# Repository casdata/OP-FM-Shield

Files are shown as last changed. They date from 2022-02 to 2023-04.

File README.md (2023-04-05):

# OP-FM-Shield
FM Synthesizer and VGM player for the Arduino Due

<p align="center">
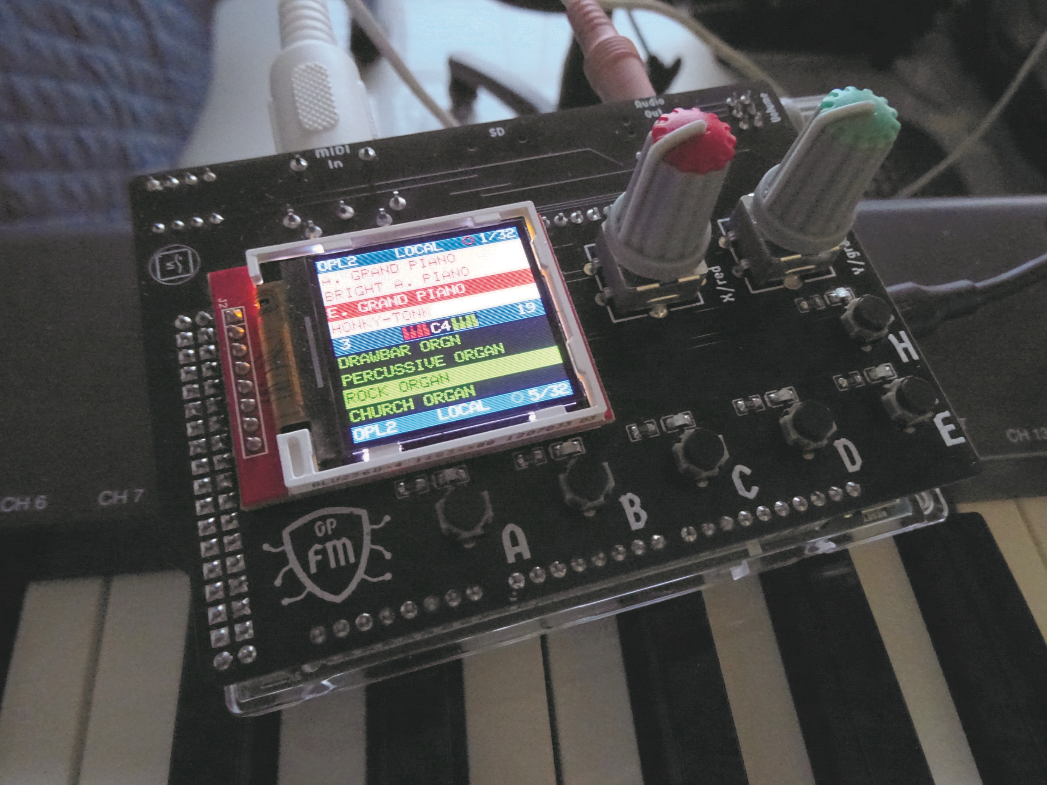
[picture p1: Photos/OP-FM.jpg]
  
</p>
                                                                                                     

The OP-FM Shield is an FM synthesizer and VGM player for the Arduino Due development board, it’s powered by the YMF262 (OPL3) sound chip from Yamaha. Is compatible with any keyboard with a 5 pin MIDI OUT port.

In Synth mode, the YMF262 can work in OPL2 or OPL3 mode depending on the selected voice, a maximum of 12 keys can be pressed simultaneously in OPL2 and 6 keys for OPL3. New OPL2 and OPL3 voices can be created from scratch, also the Included voices in the firmware can be modified, the user has access to almost all the parameters of the YMF262, why almost all? The five native rhythms are not available. 

Synth mode has two options on how the keyboard can be used, in the first option (first screen) the synth uses all the keyboards for the selected voice, in the second option, the keyboard is divided into two, one-half keyboard for red voice and the other half for the green voice, an OPL3 voice can only be selected in the red voice half and the maximum number of simultaneous keys are downgraded to five. 

In VGM player mode the keyboard is disabled, all the VGM songs are readed from the SD card. This mode also has the option to extract the voices of the VGM, they’re stored in a temporary folder that can be accessed from synth mode, those extracted voices must be saved manually or they’re deleted when other voices are extracted from a VGM.

VGM files for the OPL, OPL2 and OPL3 are compatible with the OP-FM, songs can be found on the internet, but before the .vgm file is transferred to the “vgm” folder in the SD card, the file must be extracted using the 7-zip app (https://www.7-zip.org).

And the best part above all is that software and hardware parts of the OP-FM Shield are open source, enjoy!

### Recommended VGM websites: 
* https://opl.wafflenet.com
* https://vgmrips.net/packs/chip/ymf262

## Board
Front            |  Back
:-------------------------:|:-------------------------:
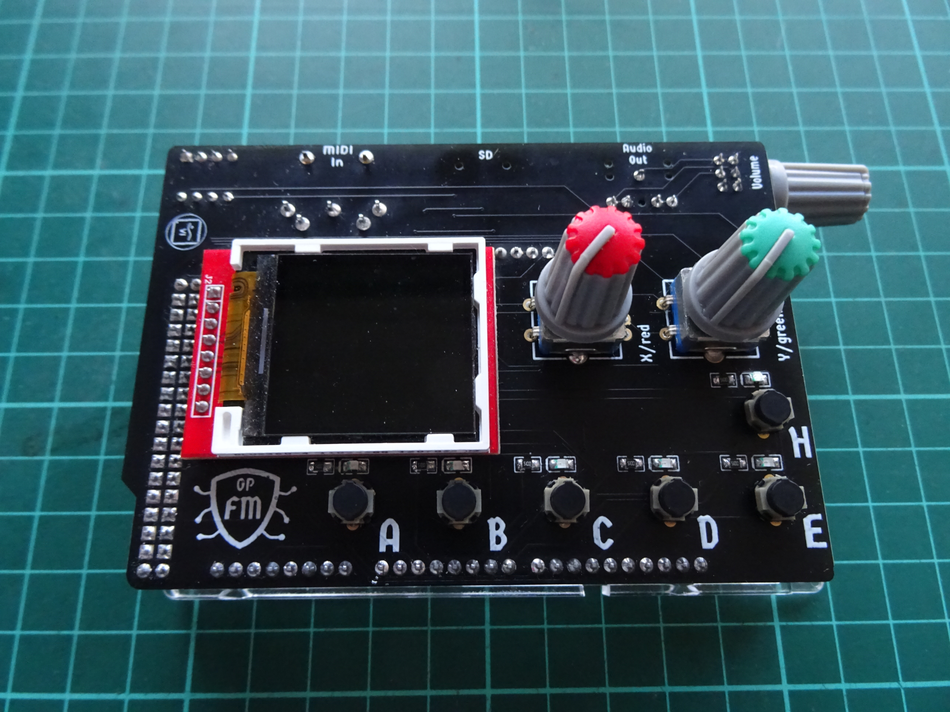
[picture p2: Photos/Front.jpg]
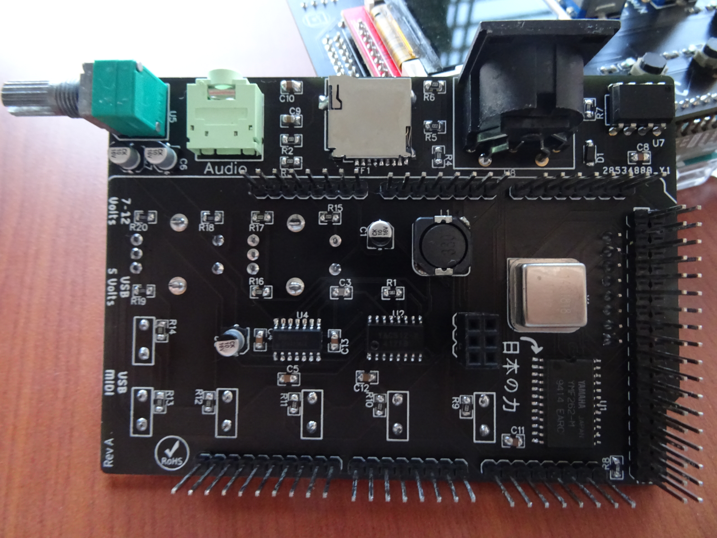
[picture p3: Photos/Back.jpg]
  |  

## Schematic Diagram
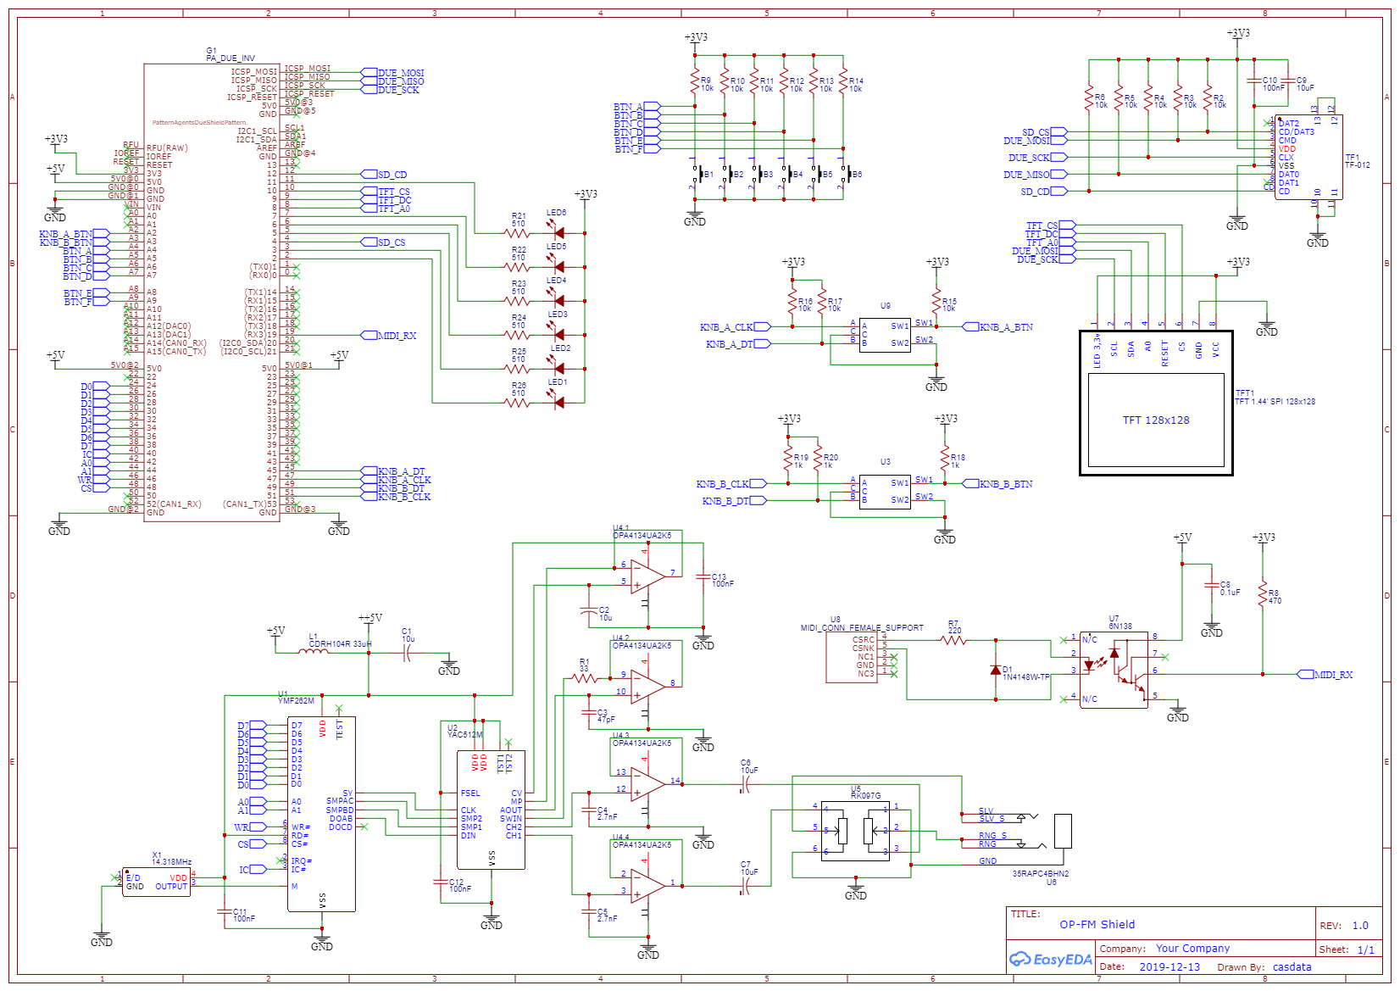
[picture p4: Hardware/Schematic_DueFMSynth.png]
Schematic
                                                                                                     
## Required Arduino Libraries
Before the firmware is uploaded, these libraries must be installed:
* MIDI Library by Francois Best (https://github.com/FortySevenEffects/arduino_midi_library)
* Adafruit GFX Library by Adafruit (https://github.com/adafruit/Adafruit-GFX-Library)
* Adafruit BusIO (https://github.com/adafruit/Adafruit_BusIO)
* Adafruit ST7735 and ST7789 Library by Adafruit (https://github.com/adafruit/Adafruit-ST7735-Library)
* Adafruit seesaw Library by Adafruit (https://github.com/adafruit/Adafruit_Seesaw)
* SD by Arduino, SparkFun (https://github.com/arduino-libraries/SD)
* Encoder by Paul Stoffregen (https://github.com/PaulStoffregen/Encoder)
* ArduinoThread by Ivan Seidel (https://github.com/ivanseidel/ArduinoThread)
* DueTimer by Ivan Seidel (https://github.com/ivanseidel/DueTimer)

## Alternative Firmware Download
The code for the firmware is available in the 'Software" folder but can also be downloaded from the Arduino Cloud (https://create.arduino.cc/editor/casdata/655ca870-2cc1-4bf0-9da4-6e03262c0709/preview)

## IMPORTANT
The shield works either with the original or the Chinese clones Arduino Due boards, but it’s recommended to use the original due to some clone boards (almost all) comes with an issue in the power supply circuit that induces noise into the MIDI port when powering it over the power jack, also in the clone boards the shield doesn't boot until the reset button in the Arduino board is pressed after its connected to a power source.

## Contact

Sergio Daniel Castañeda N. - [@twitter_handle](https://twitter.com/CasdataSergio) - casdata@gmail.com

Website: http://casnisoft.weebly.com

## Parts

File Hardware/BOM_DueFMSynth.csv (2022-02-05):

ID | Name | Designator | Footprint | Quantity | Manufacturer Part | Manufacturer | Supplier | Supplier Part | Price
1 | PUSH_BUTTON_2Pini | B1,B2,B3,B4,B5,B6 | PUSH2 | 6 | PUSH_BUTTON_2Pini
2 | 10u | C1,C2 | CAP-D4.0XH5.5 | 2
3 | 47pF | C3 | 0805 | 1
4 | 2.7nF | C4,C5 | 0805 | 2
5 | 10uF | C6,C7 | CAP-D4.0XH5.5 | 2
6 | 0.1uF | C8 | 0805 | 1
7 | 10uF | C9 | 0805 | 1
8 | 100nF | C10,C11,C12,C13 | 0805 | 4
9 | 1N4148W-TP | D1 | SOD-123_L2.8-W1.8-LS3.7-RD | 1 | 1N4148W-TP | MCC | LCSC | C77978 | 0.014
10 | PA_DUE_INV | G1 | PA_DUE_INV | 1 |  | Arduino
11 | CDRH104R 33uH | L1 | CDRH104R | 1 | CDRH104R
12 | 17-21SURC/S530-A2/TR8 | LED1,LED2,LED3,LED4,LED5,LED6 | LED-0805 | 6 | 17-21SURC/S530-A2/TR8 | EVERLIGHT | LCSC | C131244 | 0.023
13 | 33 | R1 | 0805 | 1
14 | 10k | R2,R3,R4,R5,R6,R9,R10,R11,R12,R13,R14,R15,R16,R17 | 0805 | 14
15 | 220 | R7 | 0805 | 1
16 | 470 | R8 | 0805 | 1
17 | 1k | R18,R19,R20 | 0805 | 3
18 | 510 | R21,R22,R23,R24,R25,R26 | 0805 | 6
19 | TF-012 | TF1 | TF-SMD_TF-012 | 1 | TF-012 | Hanbo Electronic | LCSC | C410350 | 0.245
20 | TFT 1.44' SPI 128x128 | TFT1 | TFT_1.44'_SPI_128X128 | 1 | TFT_ILI9163C
21 | YMF262M | U1 | SOP24 | 1
22 | YAC512M | U2 | SOP-16_L10.0-W3.9-P1.27-LS6.0-BL | 1
23 | Rotary Encoder knob | U3,U9 | ROTARY_ENCODER | 2 | Rotary Encoder
24 | RK097G | U5 | RK097G | 1 | RK097G
25 | 35RAPC4BHN2 | U6 | 35RAPC4BHN2 | 1
26 | 6N138 | U7 | DIP-8_L9.8-W6.6-P2.54-LS7.6-BL | 1 | 6N138 | Isocom Components | LCSC | C255743 | 0.634
27 | MIDI_CONN_FEMALE_SUPPORT | U8 | DIN_5_FEMALE_SUPPORT | 1
28 | 14.318MHz | X1 | DIP_4P | 1
29 | OPA4134UA2K5 | U4 | SOIC14N | 1

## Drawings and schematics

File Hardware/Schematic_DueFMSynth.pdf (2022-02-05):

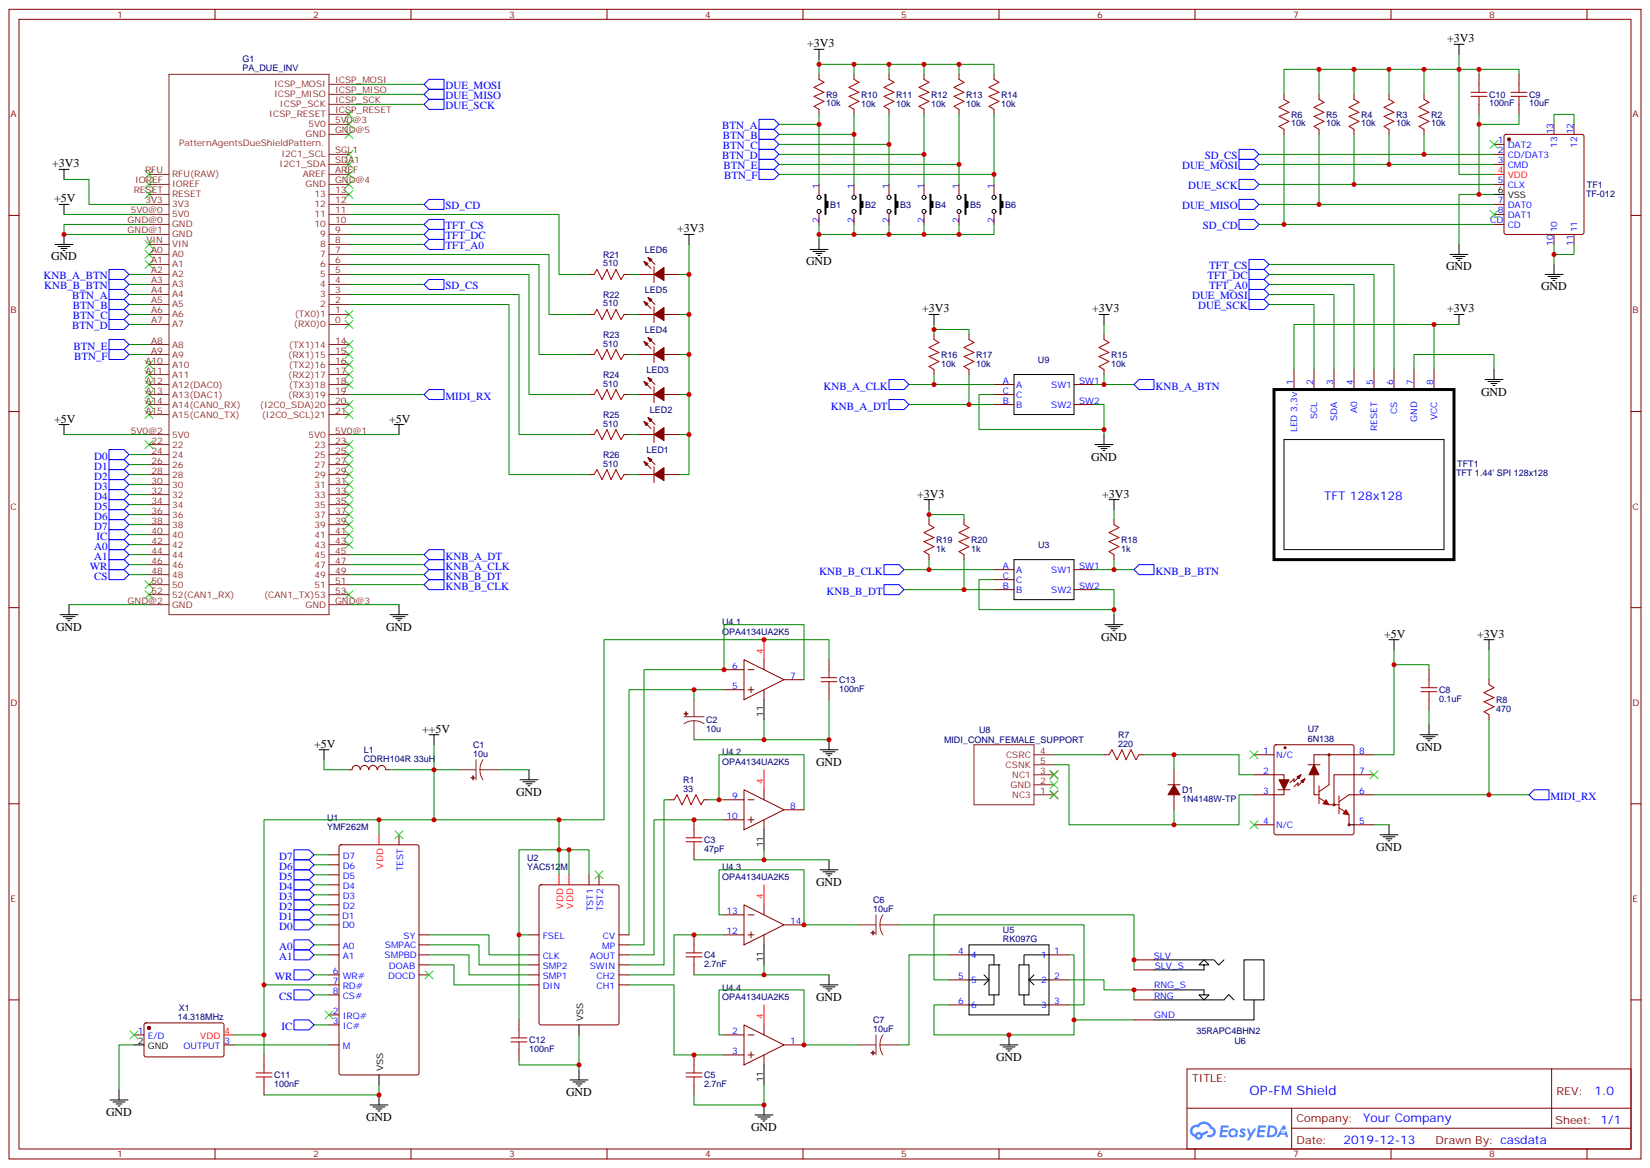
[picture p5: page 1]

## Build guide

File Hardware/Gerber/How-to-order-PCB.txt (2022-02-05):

How to Order PCB

Please refer to:
https://docs.easyeda.com/en/PCB/Order-PCB

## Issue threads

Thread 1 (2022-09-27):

the model of Rotary Encoder

Landau-Randall, 2022-09-27:
could you tell me the model of rotary Encoder knob?

casdata, 2022-09-29:
Hi Landau-Randall,  the model is the EC11, you can find it in [Aliexpress ](https://www.aliexpress.com/item/4000755931777.html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,scm-url:1007.13339.291025.0,pvid:340e41b6-d87d-4f35-93a1-3b553f208879,tpp_buckets:668%232846%238113%231998&pdp_ext_f=%7B"sku_id"%3A"10000007329345591"%2C"sceneId"%3A"3339"%7D&pdp_npi=2%40dis%21USD%212.72%212.72%21%21%21%21%21%40210312ee16644289897832056e1a16%2110000007329345591%21rec)

Ming-Kerr, 2023-04-04:
Hello.
I just completed a build and it booted first go.
I chose EC11 24 indent full step and have a strange problem.
The encoders turn the opposite way they are supposed to.
Is there an easy fix in the code to reverse the rotation direction?
Cheers.
Phil.

Ming-Kerr, 2023-04-04:
To solve my own problem, lol, I found the part in the code and reversed the logic:

void checkLimitOfKnob(int selectedKnob){

    switch(selectedKnob){
        case 0:
        if(knobACount < 0){
            knobACount = 0;
            knobA.write(0);
            **knobARight** = true;
        }
        else if(knobACount > 0){
            knobACount = 0;
            knobA.write(0);
            **knobALeft** = true;
            //knobA.write(maxLimit * 2);
        }
        break;
        case 1:
        if(knobBCount < 0){
            knobBCount = 0;
            knobB.write(0);
            **knobBRight** = true;
        }
        else if(knobBCount > 0){
            knobBCount = 0;
            knobB.write(0);
            **knobBLeft** = true;
            //knobB.write(maxLimit * 2);
        }
        break;
    }

casdata, 2023-04-05:
Hi Ming-Kerr, thanks for pointing out the issue and solving it.

Closed 2023-04-05.

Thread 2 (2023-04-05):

Versions used in compile

Ming-Kerr, 2023-04-05:
Hello.
Can you reply with the versions used for compile: Arduino IDE and the main include libraries please?

I cannot get the software to read the SDcard and have had this problem before in other apps due to library versions incompatibility.

Thanks.

casdata, 2023-04-05:
Hi Mr. Ming-Kerr, I just compile and test the board on a PC without Arduino, a clean install, and it worked with the Arduino IDE 2.0.3, the used libraries are the last available versions:
MIDI Library by Francois Best (5.0.2)
Adafruit GFX Library by Arduino (1.11.5)
Adafruit BusIO (1.14.1)
Adafruit ST7735 and ST7789 Libray by Adafruit (1.10.0)
Adafruit seesaw Library by Adafruit (1.6.3)
SD by Arduino, SparkFun (1.2.4)
Encoder by Paul Stoffregen (1.4.2)
ArduinoThread by Ivan Seidel (2.1.1)
DueTimer by IvanSeidel (1.4.7)

I notice that I forgot to add the "SD by Arduino, SparkFun" library in the README, so please check that's installed. Also when installing Adafruit GDX Library and the Adafruit ST7735 and ST7789 Library from the library manager allow the installation of all the dependencies or companion libraries when prompted.

Hope this fixes your issue :)

Ming-Kerr, 2023-04-11:
I have it fully working now.
I had two problems:

1) the VGM folder doesn't seem to read subfolders. I'd put the vgm files in subfolders :)
2) The first YMF262 I installed was faulty. Luckily I had another one...

All good!

Closed 2023-04-05.

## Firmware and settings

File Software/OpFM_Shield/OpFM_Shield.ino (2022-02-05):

#include <Arduino.h>
#include <SPI.h>
#include <SD.h>
#include <MIDI.h>
#include <Adafruit_GFX.h>
#include <Fonts/FreeMono9pt7b.h>
#include <Adafruit_ST7735.h> 
#include <Encoder.h>
#include <Thread.h>
#include <DueTimer.h>
#include "Opl3.h"
#include "ScreenActivity.h"
#include "LandSpace.h"
#include "midi_voices.h"
#include "logo.h"


Thread screenThread = Thread();

Adafruit_ST7735 tft = Adafruit_ST7735(__CS, 8,__DC);


MIDI_CREATE_INSTANCE(HardwareSerial, Serial1, MIDI);


Opl3 *opl3;
File voicesFolder;
File vgmFolder;
File tempFolder;

Screen currentScreen;
Screen beforeSaveScreen = OPERATOR;

ScreenActivity *screenActivity;

KeyMode currentKeyMode;
KeyMode previousKeyMode;
Instrument currentInstrument;

String mainInstrumentVoice = "testName";
String cleanMainInstrumentVoice = "";
String preMainInstrumentVoice = "";
OpMode mainInstrumentOpMode = OP2;

OpMode instrumentAOpMode = OP2;
OpMode instrumentBOpMode = OP2;

//unsigned long cycleTime = 0;

bool internalBtnState = false;
bool nextSong = false;
bool autoPlayIt = false;
bool vgmPlay = false;
bool vgmPause = true;
bool vgmAutoPlay = false;
bool vgmGenVoice = false;
 
uint32_t vgmPC = 0;

uint8_t opType = 3;

bool op4op2Set = true;

MemState memState = LOCAL_FOLDER;
//bool localOrSD1 = true;
bool localOrSD2 = true;
bool setNotepoint = false;
int notepoint = 60;

bool newInstrument = false;
bool setChanges = false;
bool overwriteIt = false;
bool onlySave = false;
bool presetChange = false;

int8_t saveCursorX = 0;
int letterSelect = 65;

bool rightBend = true;

//OPERATOR DATA
int opCurrentPage = 1;
int opCurrentPosition = 1;
int opCurrentPositionInPage = 1;

int selectedOp = 1;

int opAttack = 0;
int opDecay = 0;
int opSustain = 0;
int opRelease = 0;

bool opTremolo = false;
bool opVibrato = false;
bool opEnvelopeType = false;
bool opKeyScaleRate = false;

int opWaveform = 0;
int opTotalLevel = 0;
int opFreMult = 0;
int opKeyScaleLevel = 0;
//END OPERATOR DATA

//CHANNEL DATA
int chCurrentPosition = 1;

int chAlgorithm = 0;
int chFeedback = 0;
//END CHANNEL DATA


Encoder knobA(KNOB_A_CLK, KNOB_A_DT);
Encoder knobB(KNOB_B_CLK, KNOB_B_DT);

/*
Encoder knobA(KNOB_A_DT, KNOB_A_CLK);
Encoder knobB(KNOB_B_DT, KNOB_B_CLK);
*/

int buttonACurrentState;
int buttonBCurrentState;
int buttonCCurrentState;
int buttonDCurrentState;
int buttonECurrentState;
int buttonFCurrentState;

int buttonAPreviousState = 1;
int buttonBPreviousState = 1;
int buttonCPreviousState = 1;
int buttonDPreviousState = 1;
int buttonEPreviousState = 1;
int buttonFPreviousState = 1;

int switchACurrentState;
int switchBCurrentState;

int switchAPreviousState = 1;
int switchBPreviousState = 1;

bool btA = false;
bool btB = false;
bool btC = false;
bool btD = false;
bool btE = false;
bool btF = false;

bool shiftBtn = false;
bool saveAccesFlag = false;
bool accesLoaded = false;

bool ledFState = false;

unsigned long currentTimeLedF = 0;

unsigned long currentTimeBtA = 0;
unsigned long currentTimeBtB = 0;
unsigned long currentTimeBtC = 0;
unsigned long currentTimeBtD = 0;
unsigned long currentTimeBtE = 0;
unsigned long currentTimeBtF = 0;

bool lockBtA = false;
bool lockBtB = false;
bool lockBtC = false;
bool lockBtD = false;
bool lockBtE = false;
bool lockBtF = false;

int knobACount = 0;
int knobBCount = 0;

bool knobARight = false;
bool knobALeft = false;
bool knobBRight = false;
bool knobBLeft = false;

bool swA = false;
bool swB = false;

bool holdSwA = false;
bool holdSwB = false;

unsigned long currentTimeSwA = 0;
unsigned long currentTimeSwB = 0;

bool lockSwA = false;
bool lockSwB = false;

bool sdCard = false;

int16_t tlVoices = 127;     //129
int16_t tl3Voices = 127;



int16_t localVoices = 0;
int16_t localVoicesPages = 0;
int16_t currentLocalVoice = 1;
int16_t currentLocalVoiceInPage = 0;
int16_t currentLocalPage = 1;

int16_t localVoicesPagesA = 0;
int16_t currentLocalVoiceInPageA = 0;
int16_t currentLocalVoiceA = 1;
int16_t currentLocalPageA = 1;

uint16_t localVoicesB = 0;
int16_t localVoicesPagesB  = 0;
int16_t currentLocalVoiceInPageB = 0;
int16_t currentLocalVoiceB = 1;
int16_t currentLocalPageB = 1;


bool voicePagerA = false;
bool voicePagerB = false;

bool vgmPager = false;

int16_t tempVoices = 0;
int16_t tempVoicesPages = 0;
int16_t currentTempVoice = 1;
int16_t currentTempVoiceInPage = 0;
int16_t currentTempPage = 1;

int16_t sdVoices = 0;
int16_t sdVoicesPages = 0;
int16_t currentSdVoice = 1;
int16_t currentSdVoiceInPage = 0;
int16_t currentSdPage = 1;

int16_t sdVoicesPagesA = 0;
int16_t currentSdVoiceInPageA = 0;
int16_t currentSdVoiceA = 1;
int16_t currentSdPageA = 1;

uint16_t sdVoicesB = 0;
int16_t sdVoicesPagesB = 0;
int16_t currentSdVoiceInPageB = 0;
int16_t currentSdVoiceB = 1;
int16_t currentSdPageB = 1;

int16_t sdVgms = 0;
int16_t sdVgmPages = 0;
int16_t currentSdVgm = 1;
int16_t currentSdVgmInPage = 0;
int16_t currentSdVgmPage = 1;

uint8_t voicesPages[9];

uint16_t voices = 0;
uint16_t voices3 = 0;

uint16_t tVoices = 0;
uint16_t tVoices3 = 0;

uint16_t vgms = 0;
/*
uint16_t voicePages = 0; 
uint16_t currentVoice = 0;
uint16_t currentVoicePage = 0;
*/


String fileNameList[9];
String fileSDNameList[9];
String fileTEMPNameList[9];

String fileNameListA[4];
String fileNameListB[4];

String fileSDNameListA[4];
String fileSDNameListB[4];

String vgmNameList[4];
String vgmSDNameList[4];

bool wait4Samples = false;
int samplesCounter = 0;

//MIDI VARIABLES 
bool ledState;

int singlePC = -1;
int singlePCA = -1;
int singlePCB = -1;

bool overrideSend2FM = false;
bool notes2FM = false;


uint8_t selectedNote = 0;
uint8_t selectedOctave = 0;

int mod = 0;
bool modTrigger = false;

int pitch = 0;
bool pitchTrigger = false;

bool pedalSustain = false;
bool pedalSustainTrigger = false;


uint8_t notes[12] = {255, 255, 255, 255, 255, 255, 255, 255, 255, 255, 255, 255};
uint8_t notesSpeed[12] = {0, 0, 0, 0, 0, 0, 0, 0, 0, 0, 0, 0};
bool notesTrigger[12] = {false, false, false, false, false, false, false, false, false ,false, false, false};
bool sustainRelease[12] = {false, false, false, false, false, false, false, false, false ,false, false, false};

uint8_t notesA[5] = {255, 255, 255, 255, 255};
uint8_t notesSpeedA[5] = {0, 0, 0, 0, 0};
bool notesTriggerA[5] =  {false, false, false, false, false};
bool sustainReleaseA[5] = {false, false, false, false, false};

uint8_t notesB[5] = {255, 255, 255, 255, 255};
uint8_t notesSpeedB[5] = {0, 0, 0, 0, 0};
bool notesTriggerB[5] =  {false, false, false, false, false};
bool sustainReleaseB[5] = {false, false, false, false, false};

uint8_t preNotes[12] = {255, 255, 255, 255, 255, 255, 255, 255, 255, 255, 255, 255};
uint8_t preNotesA[5] = {255, 255, 255, 255, 255};
uint8_t preNotesB[5] = {255, 255, 255, 255, 255}; 
//END MIDI VARIABLES

bool chEnableA[9] = {true, true, true, true, true, true, true, true, true};
bool chEnableB[9] = {true, true, true, true, true, true, true, true, true};


void initAll();
bool initSD();
void getLocalVoicePageList(uint16_t page);
void getLocalVoicePageListA(uint16_t page);
void getLocalVoicePageListB(uint16_t page);
void loadLocalVoice(uint16_t voiceIndex);
void loadTEMPorSDVoice(uint16_t voiceIndex, int opt, bool sdVo);
void loadVoice2OPL2(uint8_t addressSector, uint8_t data, uint8_t opIndex);
void loadVoice2OPL3(uint8_t addressSector, uint8_t data, uint8_t opIndex);
void checkNative4OPChannels(bool opl2);

void readMIDIKeyboard();
void convertMidiToNote(int myNote);
void sendNotes2FM();
void cleanSynthNotes();
void cleanANotes();
void cleanSplitNotes();
void stateChecker();
void readKnobsButtons();
void readButtons();
void checkUserInput();
void accessBtnsUserInput();
void modeAUserInput();
void modeBUserInput();
void modeCUserInput();
void operatorUserInput();
void channelUserInput();
void saveInsUserInput();
void saveMessageUserInput();
void overwriteSaveUserInput();
void getChannelOpType();
void loadChannelData();
void loadOperatorData();
void checkLimitOfKnob(int selectedKnob);
void updateKnobs();
void updateExtraData();
void resetKnobSwitchs();
void setScreen(Screen newScreen);
String selectVoice2Page(uint8_t voiceIndex, uint8_t nameListIndex);
uint8_t getVoiceProgmemAt(int voiceIndex, int byteIndex);
void setLocalVoicesTotals();
void setSDVoicesTotals();
String getVoiceNameSDorTEMP(String entryName, bool sdVo);
//String getVoiceNameSD(String entryName);
String getVgmNameSD(String entryName);
void getTEMPVoicePageList(uint16_t page);
void getSDVoicePageList(uint16_t page);
void getVGMPageList(uint16_t page);
void getSDVoicePageListA(uint16_t page);
void getSDVoicePageListB(uint16_t page);
bool isOp2(String entryName);
void createOP2Voice();
void createOP4Voice();
void updateCurrentSDInPage(int16_t temp);
void updateCurrentTEMPInPage(int16_t temp);
void updateCurrentSdVgmInPage(int16_t temp);
void updateCurrentSDInPageA(int16_t temp);
void updateCurrentSDInPageB(int16_t temp);
void updateCurrentLocalInPage(int16_t temp);
void updateCurrentLocalInPageA(int16_t temp);
void updateCurrentLocalInPageB(int16_t temp);
void saveInstrument();
void saveTempVoice(String vgmStr, int tempPC, int tempCh, bool isOPl3);
bool isAOp4Voice(int tempCh);
bool dontExistTempVoice(int tempCh, bool isOPl3);
void voiceNameToSaveScreen();
bool checkIfVoiceExist();
void findSavedFile(String fileName);
int tlFix(int tlData);
void loadVoiceVolumeRegistersOPL2();
void loadVoiceVolumeRegistersOPL3();
bool isCompatibleVGMFile();
void incVgmSong();
void vgmPlayer();
void generateOP12Voices();
bool isKOn(int tempData);
void clearTEMPFolder();
void startUpSequence();
void releaseShiftBtn();
bool saveBtnAccess(uint8_t selectedBtn);
bool loadBtnAccess(uint8_t selectedBtn);
bool findSDVoice(String vName);
bool findSDVoiceA(String vName);
bool findSDVoiceB(String vName);
void blinkFLed();
void swapMidiLed();
void waitSamples(int nSamples);



void debugReadThis(){
  //Serial.print("S: ");
        
  /*
  for(int i = 0; i < 12; i++){
    Serial.print(notes[i]);              
    Serial.print(" ");
  }   
  Serial.println(""); 
  Serial.println("");
  */

  /*
  for(int i = 0; i < 5; i++){
    Serial.print(notesA[i]);              
    Serial.print(" ");
  }   
  Serial.println(""); 
  Serial.println("");
  */
  
}

/*
void tempoCount(){
  if(bpmCount == 4294967295)
    bpmCount = 0;
  else
    bpmCount++;

  if(newBpm){
    newBpm = false;
    Timer4.stop();
    Timer4.start(bpm);
  }
}
*/

void renderScreen(){
  screenActivity->render(&tft);
}

void countSample(){
  if(wait4Samples){
    samplesCounter--;
    if(samplesCounter < 0)
      wait4Samples = false;
  }
}


void setup() {

  setLocalVoicesTotals();

  getLocalVoicePageList(currentLocalPage);
  getLocalVoicePageListA(currentLocalPageA);
  getLocalVoicePageListB(currentLocalPageB);

  initAll();


  opl3->setDAM(true);
  opl3->setDVB(true);

  loadLocalVoice(1);

  screenThread.onRun(renderScreen);
  screenThread.setInterval(1);

  Timer7.attachInterrupt(countSample);
  Timer7.setFrequency(44100);

}

void loop() {
  // put your main code here, to run repeatedly:

  //Serial.println((micros() - cycleTime));
  //cycleTime = micros();

  readKnobsButtons();
  readButtons();
  updateKnobs();
  
  readMIDIKeyboard();

  screenActivity->update(&tft);

  updateExtraData();

  if(saveAccesFlag)
    blinkFLed();

  if(notes2FM)
    sendNotes2FM();
  
  if(vgmPlay){

    Timer7.start();

    do{
      screenActivity->update(&tft);
      updateExtraData();
      screenActivity->render(&tft);

      vgmPlayer();

    } while (autoPlayIt || nextSong);

    Timer7.stop();

  }
  
  stateChecker();

  checkUserInput();

  resetKnobSwitchs();

  if(screenThread.shouldRun())
    screenThread.run();
   
}

void createOP2Voice(){
  //localOrSD1 = false;
  memState = SD_FOLDER;

  opl3->reStart(true);

  newInstrument = true;

  mainInstrumentVoice = "UNTITLED_OP2";
  mainInstrumentOpMode = OP2;
  
  chAlgorithm = 0;

  checkNative4OPChannels(true);
  
  opl3->setCNT(chAlgorithm, 1);
  uint8_t tempByte = opl3->getRegisterAtAddress(0xC0, 1, 1);
  opl3->loadAllChannelsOpl2(0xC0, tempByte, 1);

  setScreen(CHANNEL);
}

void createOP4Voice(){

  //localOrSD1 = false;
  memState = SD_FOLDER;

  opl3->reStart(true);

  newInstrument = true;
  
  mainInstrumentVoice = "UNTITLED_OP4";
  mainInstrumentOpMode = OP4;

  chAlgorithm = 2;

  checkNative4OPChannels(false);
  
  opl3->setCNT(chAlgorithm, 1);
  uint8_t tempByte = opl3->getRegisterAtAddress(0xC0, 1, 1);
  opl3->loadAllChannelsOpl3(0xC0, tempByte, 1);
          
  tempByte = opl3->getRegisterAtAddress(0xC0, 1, 3);
  opl3->loadAllChannelsOpl3(0xC0, tempByte, 3);

  setScreen(CHANNEL);
}

void getTEMPVoicePageList(uint16_t page){
  if(page > tempVoicesPages)
    page = tempVoicesPages;
  if(page < 1)
    page = 1;

  page--;

  int startPoint = (0 + (page * 9));
  int endPoint = (8 + (page * 9));

  int currentIndex = 0;
  uint8_t internalIndex = 0;  

  for(int i = 0; i < 9; i++){
    fileNameList[i] = " ";
    fileTEMPNameList[i] = " ";
  }

  tempFolder.rewindDirectory();
  while(true){
    File entry = tempFolder.openNextFile();
    if(!entry)
      break;

    if(currentIndex > endPoint)
      break;
    
    if(!entry.isDirectory()){
      if((currentIndex >= startPoint) && (currentIndex <= endPoint)){
        fileTEMPNameList[internalIndex] = String(entry.name());
        fileNameList[internalIndex] = getVoiceNameSDorTEMP(String(entry.name()), false);

        internalIndex++;
      }
    }

    currentIndex++;
  }

}

void getSDVoicePageList(uint16_t page){
  if(page > sdVoicesPages)
    page = sdVoicesPages;
  if(page < 1)
    page = 1;

  page--;

  int startPoint = (0 + (page * 9));
  int endPoint = (8 + (page * 9));

  int currentIndex = 0;
  uint8_t internalIndex = 0;  

  for(int i = 0; i < 9; i++){
    fileNameList[i] = " ";
    fileSDNameList[i] = " ";
  }

  voicesFolder.rewindDirectory();
  while(true){
    File entry = voicesFolder.openNextFile();
    if(!entry)
      break;

    if(currentIndex > endPoint)
      break;
    
    if(!entry.isDirectory()){
      if((currentIndex >= startPoint) && (currentIndex <= endPoint)){
        fileSDNameList[internalIndex] = String(entry.name());
        fileNameList[internalIndex] = getVoiceNameSDorTEMP(String(entry.name()), true);

        internalIndex++;
      }
    }

    currentIndex++;
  }

}

void getVGMPageList(uint16_t page){
  if(page > sdVgmPages)
    page = sdVgmPages;
  if(page < 1)
    page = 1;

  page--;

  int startPoint = (0 + (page * 4));
  int endPoint = (3 + (page * 4));

  int currentIndex = 0;
  uint8_t internalIndex = 0;  

  for(int i = 0; i < 4; i++){
    vgmNameList[i] = " ";
    vgmSDNameList[i] = " ";
  }
  

  vgmFolder.rewindDirectory();
  while(true){
    File entry = vgmFolder.openNextFile();
    if(!entry)
      break;

    if(currentIndex > endPoint)
      break;
    
    if(!entry.isDirectory()){
      if((currentIndex >= startPoint) && (currentIndex <= endPoint)){
        vgmSDNameList[internalIndex] = String(entry.name());
        vgmNameList[internalIndex] = getVgmNameSD(String(entry.name()));
    
        internalIndex++;
      }
    }

    currentIndex++;
  }
  
}

void getSDVoicePageListA(uint16_t page){
  if(page > sdVoicesPagesA)
    page = sdVoicesPagesA;
  if(page < 1)
    page = 1;

  page--;

  int startPoint = (0 + (page * 4));
  int endPoint = (3 + (page * 4));

  int currentIndex = 0;
  uint8_t internalIndex = 0;  

  for(int i = 0; i < 4; i++){
    fileNameListA[i] = " ";
    fileSDNameListA[i] = " ";
  }

  voicesFolder.rewindDirectory();
  while(true){
    File entry = voicesFolder.openNextFile();
    if(!entry)
      break;

    if(currentIndex > endPoint)
      break;
    
    if(!entry.isDirectory()){
      if((currentIndex >= startPoint) && (currentIndex <= endPoint)){
        fileSDNameListA[internalIndex] = String(entry.name());
        fileNameListA[internalIndex] = getVoiceNameSDorTEMP(String(entry.name()), true);

        internalIndex++;
      }
    }

    currentIndex++;
  }

}

void getSDVoicePageListB(uint16_t page){
  if(page > sdVoicesPagesB)
    page = sdVoicesPagesB;
  if(page < 1)
    page = 1;

  page--;

  int startPoint = (0 + (page * 4));
  int endPoint = (3 + (page * 4));

  int currentIndex = 0;
  uint8_t internalIndex = 0;  

  for(int i = 0; i < 4; i++){
    fileNameListB[i] = " ";
    fileSDNameListB[i] = " ";
  }

  voicesFolder.rewindDirectory();
  while(true){
    File entry = voicesFolder.openNextFile();
    if(!entry)
      break;

    if(currentIndex > endPoint)
      break;
    
    if(!entry.isDirectory()){
      if((currentIndex >= startPoint) && (currentIndex <= endPoint)){
        
        if(isOp2(entry.name())){
          fileSDNameListB[internalIndex] = String(entry.name());
          fileNameListB[internalIndex] = getVoiceNameSDorTEMP(String(entry.name()), true);
        }
        else{
          fileSDNameListB[internalIndex] = "null";
          fileNameListB[internalIndex] = "<OP4 NO COMPATIBLE>";
        }
        internalIndex++;
      }
    }

    currentIndex++;
  }

}

bool isOp2(String entryName){
  bool temp = false;

  File selectedFile = SD.open("/voices/"+entryName);

  if(selectedFile){
    if(selectedFile.available()){
      int selectedByte = selectedFile.read();

      if(selectedByte == 0x3C)
        temp = true;
    }
  }

  selectedFile.close();
  
  return temp;
}

String getVoiceNameSDorTEMP(String entryName, bool sdVo){
  String a = "";

  File selectedFile;

  if(sdVo)
    selectedFile = SD.open("/voices/"+entryName);
  else
    selectedFile = SD.open("/temp/"+entryName);

  if(selectedFile){

    int selectedByte = 0;
    int minPoint = 0;
    int i = 1;

    if(selectedFile.available())
      selectedByte = selectedFile.read();

    if(selectedByte == 0x3C)                             //OP2
      minPoint = 12;
    
    else if(selectedByte == 0x78)                        //OP3
      minPoint = 23;
    

    if(minPoint > 0){
      while(selectedFile.available()){
        selectedByte = selectedFile.read();

        if(i >= minPoint){
          if(selectedByte != 0)
            a += (char)selectedByte;
        }
        i++;
      }
    }
  }

  selectedFile.close();

  return a;
}


String getVgmNameSD(String entryName){
  String a = "";

  File selectedFile = SD.open("/vgm/"+entryName);

  if(selectedFile){

    int selectedByte = 0;
    int countIt = 0;

    uint32_t tempSize = selectedFile.size();

    if(tempSize > 0){
      uint32_t tempTarget = tempSize - 1000;

      if(tempTarget < 0)
        tempTarget = 0;

      if(selectedFile.seek(tempTarget)){

        bool lockA = false;
        bool lockB = false;
        bool lockC = false;

        while(selectedFile.available()){
          selectedByte = selectedFile.read();

          if(lockA && lockB && lockC){
            if(countIt > 41)  //
              break;
            else{
              if(selectedByte != 0 && selectedByte < 0x7F && selectedByte >= 0x20){
                a += (char)selectedByte;
                countIt++;
              }
            }
            
          }//END if(lockA && lockB && lockC)
          else{
            if(selectedByte == 0x47)
              lockA = true;
            else if(selectedByte == 0x64)
              lockB = true;
            else if(selectedByte == 0x33){
              lockC = true;
              selectedByte = selectedFile.read();
            }
            else{
              lockA = false;
              lockB = false;
              lockC = false;
            }
          }//END else
          
        }//END while()

      }//END if

    }
  }

  selectedFile.close();

  return a;
}


void getLocalVoicePageList(uint16_t page){
  if(page > localVoicesPages)
    page = localVoicesPages;
  if(page < 1)
    page = 1;

  page--;

  int startPoint = (1 + (page * 9));
  int endPoint = (9 + (page * 9));

  uint8_t internalIndex = 0;

  for(int i = 0; i < 9; i++)
    fileNameList[i] = " ";

  for(int i = 1; i <= localVoices; i++){
    if((i >= startPoint) && (i <= endPoint)){
      fileNameList[internalIndex] = selectVoice2Page(i, internalIndex);
      internalIndex++;
    }

    if(i > endPoint)
      break;
  }
}

void getLocalVoicePageListA(uint16_t page){
  if(page > localVoicesPagesA)
    page = localVoicesPagesA;
  if(page < 1)
    page = 1;

  page--;

  int startPoint = (1 + (page * 4));
  int endPoint = (4 + (page * 4));

  uint8_t internalIndex = 0;

  for(int i = 0; i < 4; i++)
    fileNameListA[i] = " ";

  for(int i = 1; i <= localVoices; i++){
    if((i >= startPoint) && (i <= endPoint)){
      fileNameListA[internalIndex] = selectVoice2Page(i, internalIndex);
      internalIndex++;
    }

    if(i > endPoint)
      break;
  }
}



void getLocalVoicePageListB(uint16_t page){
  if(page > localVoicesPagesB)
    page = localVoicesPagesB;
  if(page < 1)
    page = 1;

  page--;

  int startPoint = (1 + (page * 4));
  int endPoint = (4 + (page * 4));

  uint8_t internalIndex = 0;

  for(int i = 0; i < 4; i++)
    fileNameListB[i] = " ";

  for(int i = 1; i <= localVoicesB; i++){
    if((i >= startPoint) && (i <= endPoint)){
      fileNameListB[internalIndex] = selectVoice2Page(i, internalIndex);
      internalIndex++;
    }

    if(i > endPoint)
      break;
  }
}


String selectVoice2Page(uint8_t voiceIndex, uint8_t nameListIndex){
  voicesPages[nameListIndex] = voiceIndex;

  String tempString = "";

  uint8_t tempData = getVoiceProgmemAt(voiceIndex, 0);

  if(tempData == 0x3C){                                                    //OPL2

    for(int i = 12; i < 30; i++){
      tempData = getVoiceProgmemAt(voiceIndex, i);

      if(tempData == 0x0)
        break;

      tempString += (char)tempData;

    }
  }
  else if(tempData == 0x78){
    for(int i = 23; i < 41; i++){
      tempData = getVoiceProgmemAt(voiceIndex, i);

      if(tempData == 0x0)
        break;
      
      tempString += (char)tempData;
    }
  }

  return tempString;

}
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

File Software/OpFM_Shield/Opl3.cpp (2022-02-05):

#include "Opl3.h"



Opl3::Opl3(){

    this->tempReg = 0;

    this->speedExpression = false;

    noteFNumberOPL3[0] = 345;   //C4
    noteFNumberOPL3[1] = 365;   
    noteFNumberOPL3[2] = 387;   //D4
    noteFNumberOPL3[3] = 410;
    noteFNumberOPL3[4] = 435;   //E4
    noteFNumberOPL3[5] = 460;   //F4
    noteFNumberOPL3[6] = 488;
    noteFNumberOPL3[7] = 517;   
    noteFNumberOPL3[8] = 547;
    noteFNumberOPL3[9] = 580;
    noteFNumberOPL3[10] = 614;
    noteFNumberOPL3[11] = 651;

    lowNoteFNumberOPL3[0] = 326;
    lowNoteFNumberOPL3[1] = 307;

    highNoteFNumberOPL3[0] = 690;
    highNoteFNumberOPL3[1] = 731;

    noteFNumberOPL2[0] = 363;   //C4
    noteFNumberOPL2[1] = 385;   
    noteFNumberOPL2[2] = 408;   //D4
    noteFNumberOPL2[3] = 432;
    noteFNumberOPL2[4] = 458;   //E4
    noteFNumberOPL2[5] = 485;   //F4
    noteFNumberOPL2[6] = 514;
    noteFNumberOPL2[7] = 544;   
    noteFNumberOPL2[8] = 577;
    noteFNumberOPL2[9] = 611;
    noteFNumberOPL2[10] = 647;
    noteFNumberOPL2[11] = 686;


    for(int i = 0; i < 18; i++){
        chConnections[i] = 0;
        chTlOp1[i] = 0;
        chTlOp2[i] = 0;
        chTlOp3[i] = 0;
        chTlOp4[i] = 0;
    }

}

void Opl3::init(bool op4Mode){   

    pinMode(IC, OUTPUT);
    pinMode(A0, OUTPUT);
    pinMode(A1, OUTPUT);
    pinMode(WR, OUTPUT);
    pinMode(CS, OUTPUT);

    pinMode(D0, OUTPUT);
    pinMode(D1, OUTPUT);
    pinMode(D2, OUTPUT);
    pinMode(D3, OUTPUT);
    pinMode(D4, OUTPUT);
    pinMode(D5, OUTPUT);
    pinMode(D6, OUTPUT);
    pinMode(D7, OUTPUT);


    digitalWrite(IC, HIGH);
    digitalWrite(A0, LOW);
    digitalWrite(A1, LOW);
    digitalWrite(WR, HIGH);
    digitalWrite(CS, HIGH);

    digitalWrite(D0, LOW);
    digitalWrite(D1, LOW);
    digitalWrite(D2, LOW);
    digitalWrite(D3, LOW);
    digitalWrite(D4, LOW);
    digitalWrite(D5, LOW);
    digitalWrite(D6, LOW);
    digitalWrite(D7, LOW);
    
    reStart(op4Mode);
    
}

void Opl3::reStart(bool op4Mode){
    reset();

    op4ModeChip = op4Mode;

    if(op4Mode)
        enableOPL3Features(true);
    else
        enableOPL3Features(false);

    setNTS(true);

    int tempAddr = 0;

    for(int i = 0; i < 9; i++){
        tempAddr = (0xC0 + i);

        write(tempAddr, 0x30);
        registersA[tempAddr] = 0x30;

        PIOC->PIO_SODR = PIO_PC19;

        write(tempAddr, 0x30);
        registersB[tempAddr] = 0x30;
    }

}

void Opl3::setSpeedExpression(bool enable){
    this->speedExpression = enable;
}

bool Opl3::getSpeedExpression(){
    return this->speedExpression;
}

void Opl3::reset(){
    digitalWrite(IC, LOW);
    delay(1);
    digitalWrite(IC, HIGH);
    
    for(int i = 0; i < 246; i++){
        registersA[i] = 0;
        registersB[i] = 0;
    }

    for(int i = 0; i < 6; i++)
        op4ChannelsA[i] = false;
    

}

void Opl3::fakeWrite(uint8_t reg, uint8_t data, bool moduleB){
    if(moduleB)
        registersB[reg] = data;
    else
        registersA[reg] = data;
}

void Opl3::write(uint8_t reg, uint8_t data, bool moduleB){
    if(moduleB)
        PIOC->PIO_SODR = PIO_PC19;

    write(reg, data);
}


void Opl3::write(uint8_t reg, uint8_t data){

    //write reg address

    PIOA->PIO_CODR = PIO_PA19;

    reg2Pins(reg);

    PIOC->PIO_CODR = PIO_PC15;
    PIOC->PIO_CODR = PIO_PC17;
    
    delayMicroseconds(2);   
    
    PIOC->PIO_SODR = PIO_PC15;
    PIOC->PIO_SODR = PIO_PC17;


    delayMicroseconds(4);   
    
    //write data 
    PIOA->PIO_SODR = PIO_PA19;

    reg2Pins(data);

    PIOC->PIO_CODR = PIO_PC15;
    PIOC->PIO_CODR = PIO_PC17;

    delayMicroseconds(2);   

    PIOC->PIO_SODR = PIO_PC15;
    PIOC->PIO_SODR = PIO_PC17;

    PIOC->PIO_CODR = PIO_PC19;

}


void Opl3::reg2Pins(uint8_t data){
    if((data & (BIT0)) == BIT0)
        PIOA->PIO_SODR = PIO_PA15;
    else
        PIOA->PIO_CODR = PIO_PA15;
        
        
    if((data & (BIT1)) == BIT1)    
        PIOD->PIO_SODR = PIO_PD1;
    else
        PIOD->PIO_CODR = PIO_PD1;
        
        
    if((data & (BIT2)) == BIT2)    
        PIOD->PIO_SODR = PIO_PD3;
    else
        PIOD->PIO_CODR = PIO_PD3;
        
        
    if((data & (BIT3)) == BIT3)    
        PIOD->PIO_SODR = PIO_PD9;
    else
        PIOD->PIO_CODR = PIO_PD9;
        

    if((data & (BIT4)) == BIT4)    
        PIOD->PIO_SODR = PIO_PD10;
    else
        PIOD->PIO_CODR = PIO_PD10;

        
    if((data & (BIT5)) == BIT5)    
        PIOC->PIO_SODR = PIO_PC2;
    else
        PIOC->PIO_CODR = PIO_PC2;
        

    if((data & (BIT6)) == BIT6)    
        PIOC->PIO_SODR = PIO_PC4;
    else
        PIOC->PIO_CODR = PIO_PC4;
    

    if((data & (BIT7)) == BIT7)    
        PIOC->PIO_SODR = PIO_PC6;
    else
        PIOC->PIO_CODR = PIO_PC6;

    
}



uint8_t Opl3::getRegisterAt(int i, bool a1Flag){
    uint8_t registerValue = 0;
    
    if(a1Flag)
        registerValue = registersB[i];
    else
        registerValue = registersA[i];

    return registerValue;    
}


uint8_t Opl3::getRegisterAtAddress(uint8_t addressSector, uint8_t channel, uint8_t opIndex){
    
    uint8_t tempAddr = getAddress(addressSector, channel, opIndex);

    uint8_t preRegister = 0;

    bool isRegisterA = true;

    if(isRegisterB(channel))
        isRegisterA = false;
  
    if(isRegisterA)
        preRegister = registersA[tempAddr];   
    else
        preRegister = registersB[tempAddr];  

    return preRegister; 

}


void Opl3::setAM(bool enable, uint8_t channel, uint8_t opIndex){
    uint8_t tempBit = 0;
    
    uint8_t tempAddr = getAddress(0x20, channel, opIndex);

    if(enable)
        tempBit = 0x80;
       
    uint8_t preRegister = 0;

    bool isRegisterA = true;

    if(isRegisterB(channel))
        isRegisterA = false;
    
  
    if(isRegisterA)
        preRegister = registersA[tempAddr] & 0x7f;   
    else
        preRegister = registersB[tempAddr] & 0x7f;   
        
    preRegister += tempBit;

    if(isRegisterA)
        registersA[tempAddr] = preRegister;
    else{
        registersB[tempAddr] = preRegister;
        PIOC->PIO_SODR = PIO_PC19;
    }            

    write(tempAddr, preRegister);
     
}

bool Opl3::getAM(uint8_t channel, uint8_t opIndex){

    bool temp = false;
    
    uint8_t tempAddr = getAddress(0x20, channel, opIndex);

    uint8_t preRegister = 0;

    bool isRegisterA = true;

    if(isRegisterB(channel))
        isRegisterA = false;
    
    if(isRegisterA)
        preRegister = registersA[tempAddr] & 0x80;   
    else
        preRegister = registersB[tempAddr] & 0x80;   
    
    if(preRegister == 0x80)
        temp = true;


    return temp;     
}
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

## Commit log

2022-02-05 Add files via upload
    Added hardware and software files.
    [BOM_DueFMSynth.csv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]
2022-02-05 Update README.md
    Added circuit schematic diagram to README.md
2022-02-06 Add files via upload
    Added board photos.
2023-04-05 Update README.md
    Added SD library in the required Arduino Libraries.
